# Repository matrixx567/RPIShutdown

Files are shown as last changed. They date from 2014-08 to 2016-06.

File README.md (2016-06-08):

RPIShutdown
===========



RPIShutdown adds a power switch to the Raspberry Pi. So it is possible to completely 
disconnect the Pi from the electrical power source.

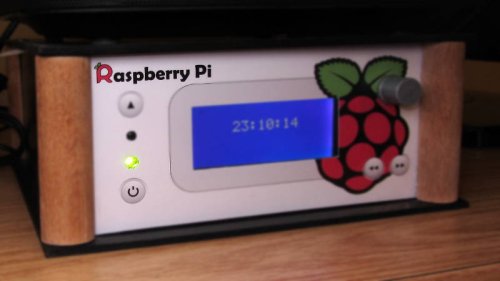
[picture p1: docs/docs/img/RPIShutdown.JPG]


How it works?
-------------
It works in the same way as the power button in the desktop computer will do.

Usually the Raspberry Pi isn't powered. If the button is pressed, the Raspberry Pi will be started.
The next press will smoothly shutdown the PI by running the `halt` command.  
If you press the button for about 4 seconds the Raspberry Pi will be hardly shutdown by 
disconnecting the power.

Installation
-------------
More information is available in the [installation notes](http://rpishutdown.readthedocs.org/content/installation-notes.html) in the documentation.

Documentation
--------------
More information are available in the [project documentation](http://rpishutdown.readthedocs.org).

other Projects
--------------

[ATXRaspi](http://lowpowerlab.com/atxraspi/): Has nearly the same functionality and you can buy it. 
But it isn't open source.

[PI2RMini](https://awjlogan.wordpress.com/2014/03/01/pi2rmini-a-proper-power-switch-for-the-raspberrypi/)

License
--------------
The MIT License (MIT)

Copyright (c) 2013 Martin Noehrer

Permission is hereby granted, free of charge, to any person obtaining a copy of
this software and associated documentation files (the "Software"), to deal in
the Software without restriction, including without limitation the rights to
use, copy, modify, merge, publish, distribute, sublicense, and/or sell copies of
the Software, and to permit persons to whom the Software is furnished to do so,
subject to the following conditions:

The above copyright notice and this permission notice shall be included in all
copies or substantial portions of the Software.

THE SOFTWARE IS PROVIDED "AS IS", WITHOUT WARRANTY OF ANY KIND, EXPRESS OR
IMPLIED, INCLUDING BUT NOT LIMITED TO THE WARRANTIES OF MERCHANTABILITY, FITNESS
FOR A PARTICULAR PURPOSE AND NONINFRINGEMENT. IN NO EVENT SHALL THE AUTHORS OR
COPYRIGHT HOLDERS BE LIABLE FOR ANY CLAIM, DAMAGES OR OTHER LIABILITY, WHETHER
IN AN ACTION OF CONTRACT, TORT OR OTHERWISE, ARISING FROM, OUT OF OR IN
CONNECTION WITH THE SOFTWARE OR THE USE OR OTHER DEALINGS IN THE SOFTWARE.

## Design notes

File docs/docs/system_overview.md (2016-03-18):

Hardware
========

Schematic
---------

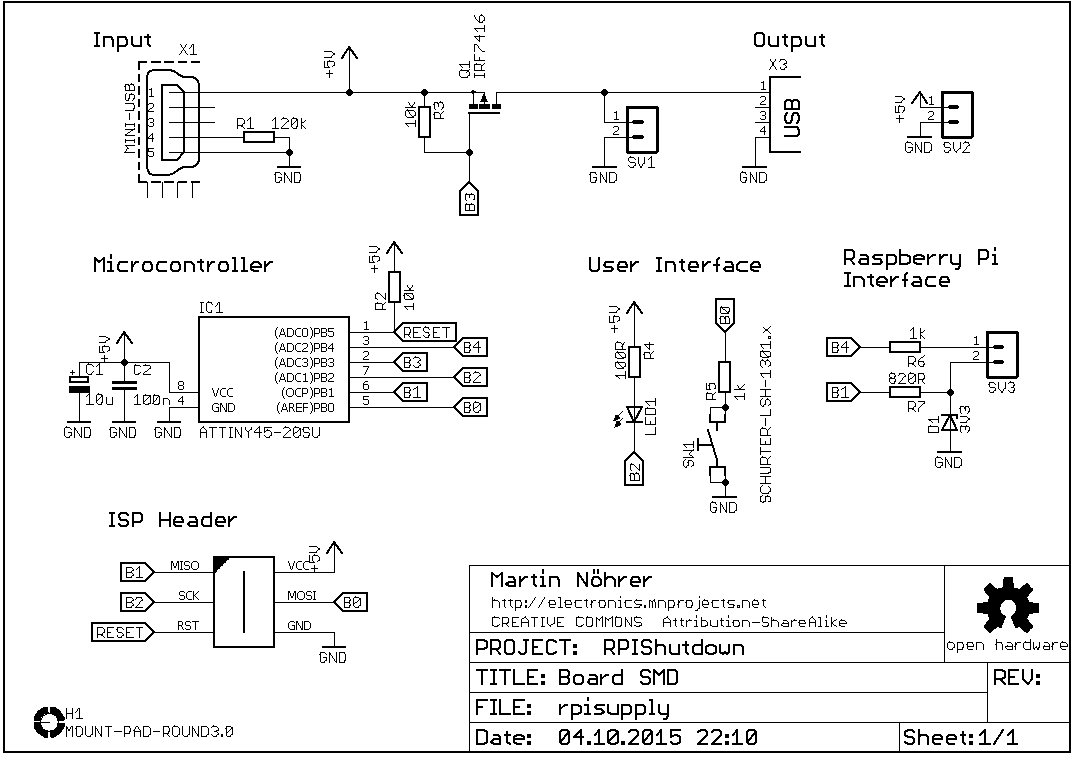
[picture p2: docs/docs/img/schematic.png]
Schematic


Description
-----------

Bill of materials
-----------------

| Qty | Part | Device | Value | VID | Vendor Part Num |
| ----- | --- | --- | --- | --- | --- |
| 1 | C1 | Cap pol | 10u | [RE] | SMD TAN.10/16 |
| 1 | C2 | Cap | 100n | [RE] | X7R-G0805 100N |
| 1 | D1 | Zener Diode | 3V3 | [RE] | SMD ZF 3,3 |
| 1 | IC1 | MC | ATTINY45-20SU | [RE] | ATTINY 45-20SU |
| 1 | LED1 | LED | green | [RE] | SMD-LED 0805 GN |
| 1 | Q1 | P-MOSFET | IRF7416 | [RE] | IRF 7416 |
| 1 | R1 | RES | 120k | [RE] | SMD-0805 120K |
| 2 | R2,R3 | RES | 10k | [RE] | SMD-0805 10,0K |
| 1 | R4 | RES | 100R | [RE] | SMD-0805 100 |
| 2 | R5,R6 | RES | 1k | [RE] | SMD-0805 1,00K |
| 1 | R7 | RES | 820R | [RE] | SMD-0805 820 |
| 1 | SW1 | Switch | SCHURTER-LSH-1301.x | [RE] | TASTER 9319 |
| 1 | X1 | Connector | MINI-USB | [RE] | LUM 2486-01 |
| 1 | X2 | Connector | AVR-ISP-6-EDGE | [RE] | MPE 087-2-006 |
| 1 | X3 | Connector | USB-A female | [RE] | USB AW |

[RE]: http://www.reichelt.at

Microcontroller Software
========================

State Machine
-------------

Settings
--------

Raspberry PI Software
========================

The Raspberry PI runs a simple script that checks periodically the signal line
of the microcontroller.

The Python script uses the preinstalled GPIO library (Raspbian).
If the microcontroller sends a shutdown command to the Raspberry PI (input line `RPI_RX` goes high)
the script executes the halt command and turn off the Raspberry PI.

Running the shutdown script as a daemon
---------------------------------------

The source folder for the Raspberry PI software also contains a shell script, which is used
to set up the RPIShutdown software as a background daemon.

[Original Script](http://blog.scphillips.com/2013/07/getting-a-python-script-to-run-in-the-background-as-a-service-on-boot/)

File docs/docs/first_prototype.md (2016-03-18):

First Prototype
========================

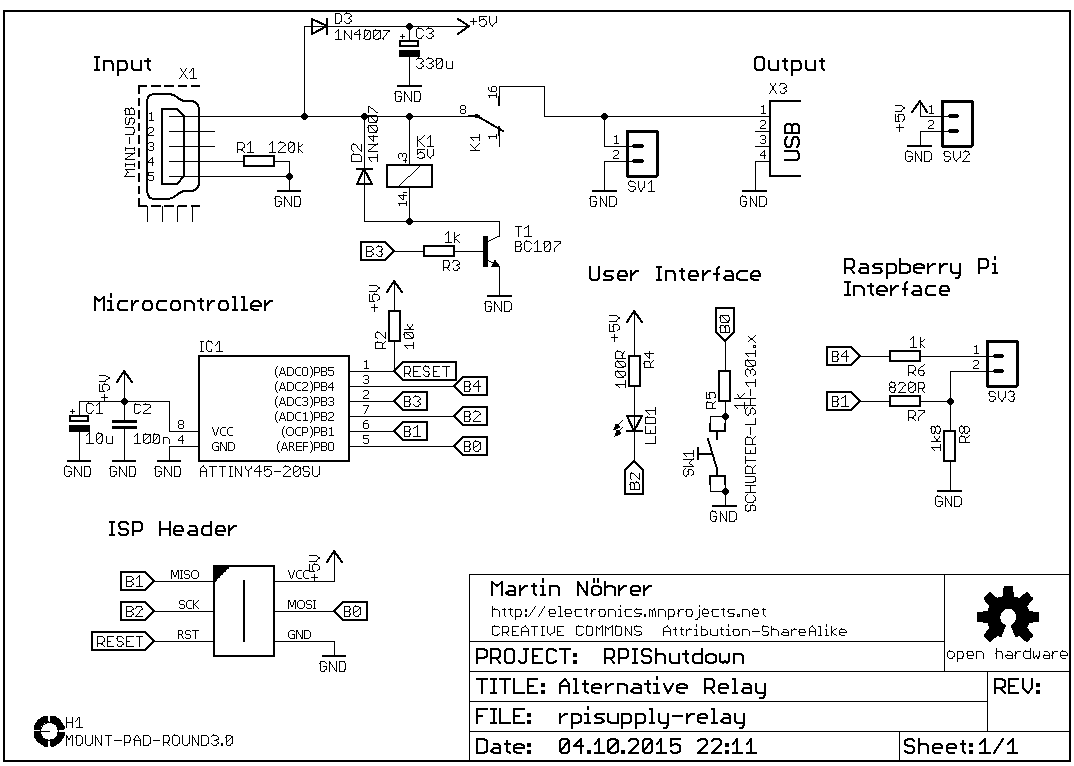
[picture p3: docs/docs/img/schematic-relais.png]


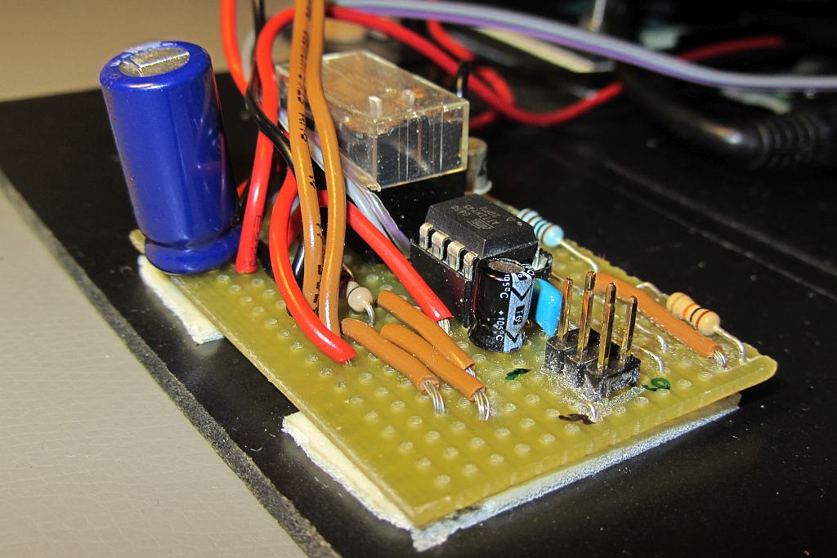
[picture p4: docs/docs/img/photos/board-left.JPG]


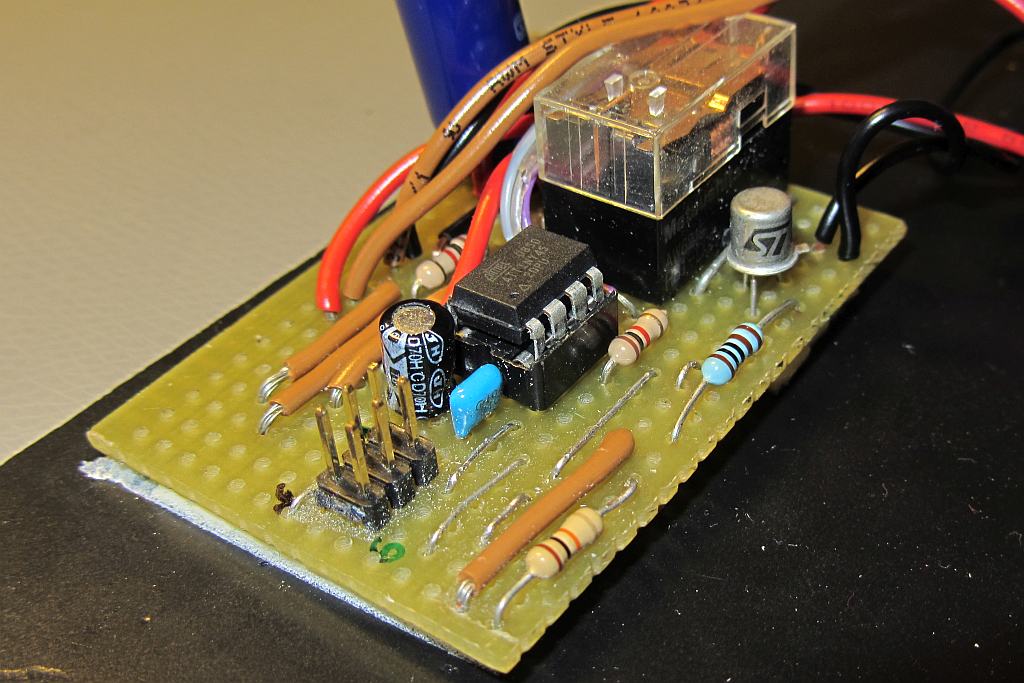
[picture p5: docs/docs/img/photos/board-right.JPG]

   
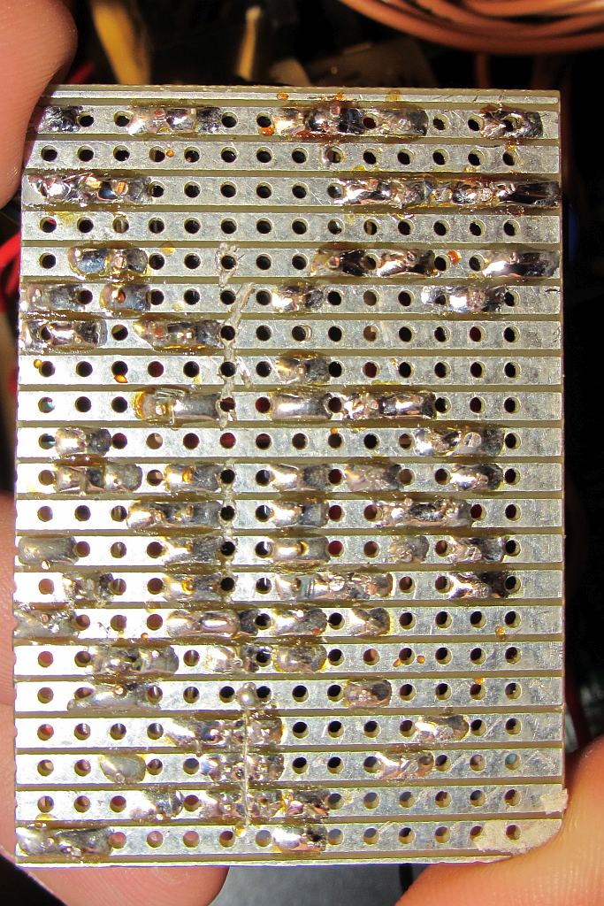
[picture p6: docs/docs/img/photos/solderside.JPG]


Microcontroller Reset Problems
------------------------------

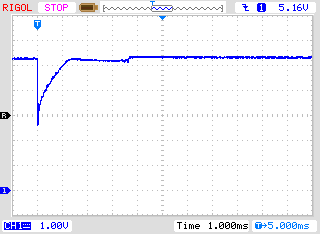
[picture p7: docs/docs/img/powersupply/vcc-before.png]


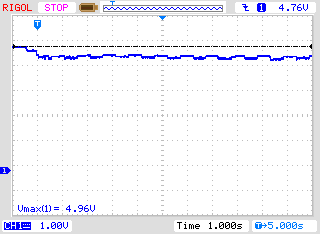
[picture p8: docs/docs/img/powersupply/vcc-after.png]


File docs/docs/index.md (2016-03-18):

RPIShutdown’s documentation!
============================

RPIShutdown adds a power switch to the Raspberry Pi. So it is possible to completely disconnect the Pi from the electrical power source.

RPIShutdown built in the RPIMpdBox

How it works?
-------------

It works in the same way as the power button in the desktop computer will do.

Usually the Raspberry Pi isn’t powered. If the button is pressed, the Raspberry Pi will be started. The next press will smoothly shutdown the PI by running the halt command. If you press the button for about 4 seconds the Raspberry Pi will be hardly shutdown by disconnecting the power.

Contents
--------

License
-------

This project is licensed under **The MIT License (MIT)**. More details will be available in the [license section](license.md).

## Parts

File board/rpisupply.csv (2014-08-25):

Bill of Materials from rpisupply.sch, 21 parts, grouped by values, as of 14.11.2013 10:41:19
Qty | Part | Value | Device | Package | Description | VID | Vendor Part Num | Description
1 | C1 | 10u | CPOL-EUSMCC | SMC_C | POLARIZED CAPACITOR, European symbol | RE | SMD TAN.10/16
1 | C2 | 100n | C-EUC0805 | C0805 | CAPACITOR, European symbol | RE | X7R-G0805 100N
1 | D1 | 3V3 | ZENER-DIODESOD80C | SOD80C | Z-Diode | RE | SMD ZF 3,3
1 | H1 | MOUNT-PAD-ROUND3.0 | MOUNT-PAD-ROUND3.0 | 3,0-PAD | MOUNTING PAD, round
1 | IC1 | ATTINY45-20SU | TINY25/45/85-20SU | SOIC8 |  | RE | ATTINY 45-20SU
1 | LED1 |  | LEDSML0805 | SML0805 | LED | RE | SMD-LED 0805 GN
1 | Q1 | IRF7416 | P-MOSFET-SO8 | SO-08 | P-Channel MOSFET | RE | IRF 7416 | Leistungs-MOSFET P-Ch SO-8 30V 10A
1 | R1 | 120k | R-EU_R0805 | R0805 | RESISTOR, European symbol | RE | SMD-0805 120K
2 | R2, R3 | 10k | R-EU_R0805 | R0805 | RESISTOR, European symbol | RE | SMD-0805 10,0K
1 | R4 | 100R | R-EU_R0805 | R0805 | RESISTOR, European symbol | RE | SMD-0805 100
2 | R5, R6 | 1k | R-EU_R0805 | R0805 | RESISTOR, European symbol | RE | SMD-0805 1,00K
1 | R7 | 820R | R-EU_R0805 | R0805 | RESISTOR, European symbol | RE | SMD-0805 820
3 | SV1, SV2, SV3 |  | MA02-1R | MA02-1
1 | SW1 | SCHURTER-LSH-1301.x | SCHURTER-LSH-1301.9319 | LSH | Schurter LSH Printmount Switches, Gullwing Leads [SMT] | RE | TASTER 9319
1 | X1 | MINI-USB | MINI-USB-SHIELD-UX60-MB-5ST | UX60-MB-5ST | MINI USB Connector | RE | LUM 2486-01 | MINI-USB
1 | X2 | AVR-ISP-6-EDGE | AVR-ISP-6-EDGE | 6PAD_ISP | 6 pin edge connector for ISP with ATMEL MCUs. | RE | MPE 087-2-006
1 | X3 |  | PN87520 | PN87520 | BERG USB connector | RE | USB AW | USB-A-female

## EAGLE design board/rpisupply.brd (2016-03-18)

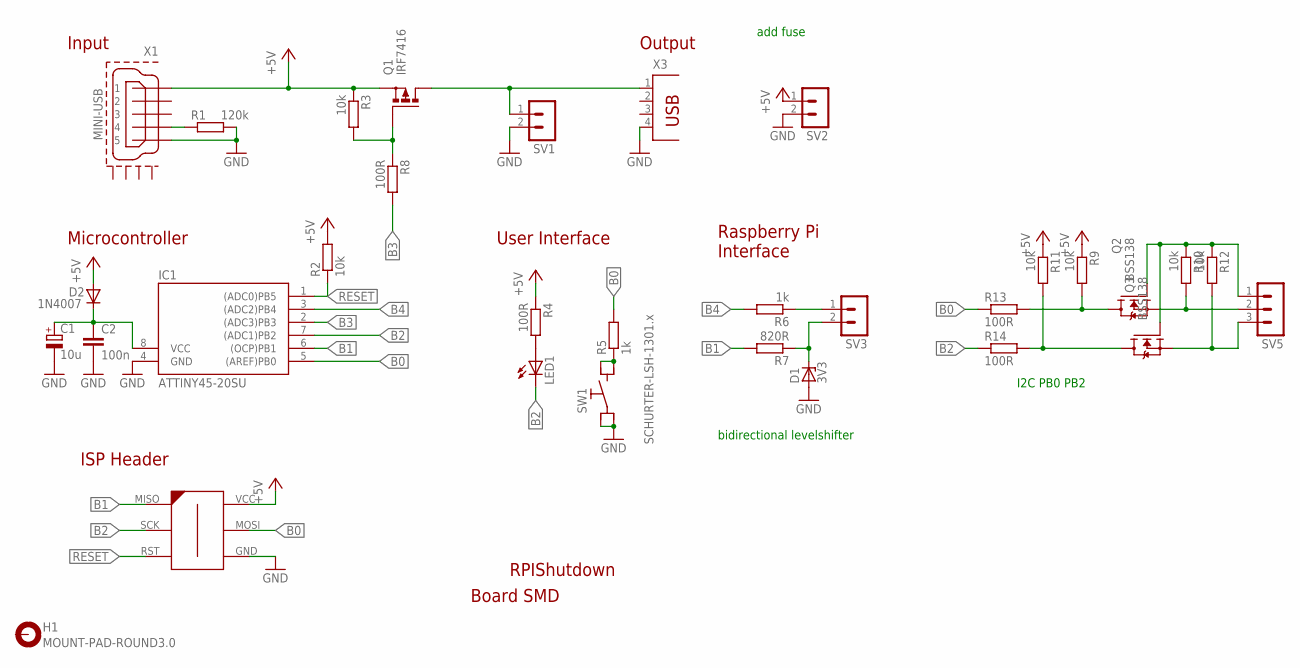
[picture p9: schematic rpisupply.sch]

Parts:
C1: 10u; SMC_C
C2: 100n; C0805
D1: 3V3; SOD80C
D2: 1N4007; MELF-MLL41
H1: MOUNT-PAD-ROUND3.0; 3,0-PAD
IC1: ATTINY45-20SU; SOIC8
LED1: LEDSML0805; SML0805
Q1: IRF7416; SO-08
Q2, Q3: BSS138; SOT23
R1: 120k; R0805
R2, R3, R9, R10, R11, R12: 10k; R0805
R4, R8, R13, R14: 100R; R0805
R5, R6: 1k; R0805
R7: 820R; R0805
SV1, SV2, SV3: MA02-1R; MA02-1
SV5: MA03-1R; MA03-1
SW1: SCHURTER-LSH-1301.x; LSH
X1: MINI-USB; UX60-MB-5ST
X2: AVR-ISP-6-EDGE; 6PAD_ISP
X3: PN87520

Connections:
+5V: D2.A, Q1.1 (S), Q1.2 (S), Q1.3 (S), R2.2, R3.1, R4.1, R9.1, R11.1, SV2.1, X1.1, X2.VCC
B0: IC1.5 ((AREF)PB0), R5.2, R13.1, X2.MOSI
B1: IC1.6 ((OCP)PB1), R7.2, X2.MISO
B2: IC1.7 ((ADC1)PB2), LED1.C, R14.1, X2.SCK
B3: IC1.2 ((ADC3)PB3), R8.2
B4: IC1.3 ((ADC2)PB4), R6.2
GND: C1.-, C2.2, D1.A, IC1.4 (GND), R1.2, SV1.2, SV2.2, SW1.C1 (C), SW1.C2 (C), X1.5, X2.GND, X3.4
unnamed: R6.1, SV3.1
unnamed: D1.C, R7.1, SV3.2
unnamed: R1.1, X1.4
unnamed: LED1.A, R4.2
unnamed: R5.1, SW1.NO1 (NO), SW1.NO2 (NO)
unnamed: Q1.4 (G), R3.2, R8.1
unnamed: C1.+, C2.1, D2.C, IC1.8 (VCC)
unnamed: Q2.1 (G), Q3.1 (G), R10.1, R12.1, SV5.1
unnamed: Q2.2 (S), R10.2, SV5.2
unnamed: Q3.3 (D), R11.2, R14.2
unnamed: Q3.2 (S), R12.2, SV5.3
unnamed: Q2.3 (D), R9.2, R13.2
unnamed: Q1.5 (D), Q1.6 (D), Q1.7 (D), Q1.8 (D), SV1.1, X3.1
RESET: IC1.1 ((ADC0)PB5), R2.1, X2.RST

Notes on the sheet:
RPIShutdown
Board SMD
ISP Header
Microcontroller
Raspberry Pi Interface
User Interface
Input
Output
bidirectional levelshifter
I2C PB0 PB2
add fuse

Board: 2 copper layers, 32 parts (0 on the bottom side), 21 nets, no tracks yet.

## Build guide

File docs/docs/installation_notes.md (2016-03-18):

Installation notes
==================

This page describes how to install the RPIShutdown to your Raspberry Pi.

Flashing the microcontroller
----------------------------

The code for the microcontroller must be compiled and flashed. In the
actual version the RPIShutdown uses a relais for switching the power of
the Raspberry Pi. The circuit is an open-collector output. The schematic derscribed in
[schematic] uses a P-Mosfet, so the code of the microcontroller must be
changed.

Connecting the RPIShutdown to the Raspberry Pi
----------------------------------------------

Note: Update electrical connections

Installing the Raspberry Pi daemon
----------------------------------

1. Copy `RPIShutdown.py` from `src_pi` to your HOME directory (e.g.`/home/pi`)
2. Move `RPIShutdown.sh` from `src_pi` to `/etc/init.d`
   `sudo mv RPIShutdown.sh /etc/init.d`
3. Change file attributes
   `sudo chmod 755 /etc/init.d/RPIShutdown.sh`
4. Startup the script
   `sudo service RPIShutdown.sh start`
5. Add script to startup
   `sudo update-rc.d RPIShutdown.sh defaults`

If you change the directory of `RPIShutdown.py`, you will also need to
change the path variable in `RPIShutdown.sh`.

With `sudo service RPIShutdown.sh status` the status of the daemon can
be checked.

Github Repository Structure
---------------------------

The project folder is organized in the following structure:

```
	RPIShutdown
	+--- board  (Schematics)
	+--- docs   (Documentation files for ReadTheDocs)
	+--- src    (Microcontroller software)
	\--- src_pi (Raspberry Pi software)
```
    
[schematic]: system_overview.md#Schematic

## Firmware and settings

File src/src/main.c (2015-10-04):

/************************************************************************
Project:  RPISupply
Title:    Add a supply switch to the raspberry pi
Author:   Martin Noehrer
Email:    martin@mnprojects.net
Homepage: https://github.com/matrixx567/RPIShutdown
File:     main.c
Date:

License:  MIT License

LICENSE:
Copyright (C) 2013 Martin Noehrer

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
THE SOFTWARE IS PROVIDED "AS IS", WITHOUT WARRANTY OF ANY KIND, EXPRESS 
OR IMPLIED, INCLUDING BUT NOT LIMITED TO THE WARRANTIES OF MERCHANTABILITY,
FITNESS FOR A PARTICULAR PURPOSE AND NONINFRINGEMENT. IN NO EVENT SHALL THE 
AUTHORS OR COPYRIGHT HOLDERS BE LIABLE FOR ANY CLAIM, DAMAGES OR OTHER 
LIABILITY, WHETHER IN AN ACTION OF CONTRACT, TORT OR OTHERWISE, ARISING 
FROM, OUT OF OR IN CONNECTION WITH THE SOFTWARE OR THE USE OR OTHER 
DEALINGS IN THE SOFTWARE.
 *************************************************************************
Software: WIN-AVR 20100110 - AVR-GCC 4.3.3, AVR Libc 1.6.7
Hardware: ATtiny45 at 8Mhz /DIV8 => 1MHz
Fuses:    LFUSE:62 HFUSE:DF EFUSE:FF
Fuses:    LFUSE:62 HFUSE:DD EFUSE:FF	new Setting
Usage:
 *************************************************************************
Pin Description:
B0: inp	Switch		 low...pressed
B1:	out	RPI-TX		 output to raspberrypi
B2:	out	Status-LED   low...LED on
B3:	out	Relay		 high...on
B4:	inp	RPI-RX		 input from raspberrypi
 *************************************************************************
Description: see documentation
 *************************************************************************
Changelog:
 *************************************************************************
contains code and ideas from:
 ************************************************************************/


 // #define USE_MOSFET

//internal 8MHz oscillator with CKDIV8
#ifndef F_CPU
#define F_CPU 1000000UL     /* 1 Mhz internal oscillator  */
#endif


#include <avr/io.h>
#include <avr/sleep.h>
#include <avr/interrupt.h>
#include <util/delay.h>


#define IRPIRX	PB4
#define ORELAY	PB3
#define OLED	PB2
#define ORPITX	PB1
#define ISWITCH	PB0


#ifdef USE_MOSFET
// use mosfet - active low
	#define RELAY_ON	PORTB &= ~(1<<ORELAY)
	#define RELAY_OFF	PORTB |= (1<<ORELAY)
#else
// use relay - active high
	#define RELAY_ON	PORTB |= (1<<ORELAY)
	#define RELAY_OFF	PORTB &= ~(1<<ORELAY)
#endif


//internal states
enum sm_states_e {
	POWER_OFF = 0,
	STARTUP,
	RUNNING,
	SHUTDOWN
};


// modes for the LED
enum led_mode_e {
	LED_OFF=0,
	LED_BLINKING,
	LED_ON
};


// states of the button
enum button_state_e{
	NO_PRESS = 0,
	SHORT_PRESS,
	LONG_PRESS
};

//direction of soft blinking LED
enum led_pwm_direction_e{
	COUNT_UP = 0,
	COUNT_DOWN
};

// counter for button's debouncing and for detecting the long press
volatile uint16_t button_cnt = 0;

// counter for detecting the delay timer overflows
volatile uint8_t delay_counter = 0;

// actual mode of the LED
volatile enum led_mode_e led_mode = LED_OFF;


//level value for soft emulated PWM
uint8_t softblink_level=0;

//direction of soft blinking LED
enum led_pwm_direction_e led_pwm_dir = COUNT_UP;

//step for softblinking LED
#define SOFTBLINK_STEP 2


/**
 * Interrupt service routine for Timer 0.
 *
 * This timer is used to detect a long press of the button
 */
ISR( TIMER0_OVF_vect )                   // every 16ms
{
	button_cnt++;


	if(led_pwm_dir == COUNT_UP){
		if(softblink_level> (255-SOFTBLINK_STEP) ){
			led_pwm_dir = COUNT_DOWN;
			softblink_level = 255;
		} else {
			softblink_level += SOFTBLINK_STEP;
		}
	} else {
		if(softblink_level<SOFTBLINK_STEP){
			led_pwm_dir = COUNT_UP;
			softblink_level = 0;
		} else {
			softblink_level -= SOFTBLINK_STEP;
		}
	}
}

/**
 * Interrupt service routine for Timer 1.
 *
 * This timer is used to generate delay functionality.
 */
ISR(TIMER1_OVF_vect) {				//every 500ms
	//if(led_mode == LED_BLINKING)
	//	PORTB ^= (1<<OLED);
	delay_counter++;
}


ISR(INT0_vect) {

}

ISR(PCINT0_vect) {

}



int main(void) {

	//internal actual state of the state machine
	enum sm_states_e states_e = POWER_OFF;

	//actual state of the button
	enum button_state_e buttonstate = NO_PRESS;

	//temporary state which is used for resetting the delay counter
	enum sm_states_e temp_states_e = POWER_OFF;


	//temporary value for soft emulated PWM
	uint8_t softblink_temp=0;



	//set direction of pins to output
	DDRB = (1 << ORELAY) | (1 << OLED) | (1 << ORPITX);

	RELAY_OFF;		//Switch off relay

	PORTB &= ~(1<<ORPITX);		//Switch off TX


	// Configure debouncing routines
	DDRB  &= ~(1<<ISWITCH);                // configure key port for input
	PORTB |= (1<<ISWITCH);                // and turn on pull up resistors

	TCCR0B = (1<<CS01)|(1<<CS00);         // divide by 64
	// overflow 0.016 sec

	TIMSK |= 1<<TOIE0;                   // enable timer interrupt

	TCCR1 |= (1<<CS13) |(1<<CS12); // Prescaler 2048
	// overflow time about 0.5 sec

	PCMSK |= (1<<PCINT0); //  tell pin change mask to listen to PB0, Switch
	PCMSK |= (1<<PCINT4); //  tell pin change mask to listen to PB4, RPIInput

	// Overflow Interrupt erlauben
	TIMSK |= (1<<TOIE1);
	GIMSK |= (1<<PCIE);
	sei();

	set_sleep_mode(SLEEP_MODE_PWR_DOWN);


	//Detecting reset of microcontroller - for debugging
	PORTB &= ~(1<<OLED);
	for(int i=0; i < 10 ; i++){
		PORTB ^= 1<<OLED;
		_delay_ms(100);
	}
	PORTB |= (1<<OLED);


	while (1) {



		buttonstate=NO_PRESS;

		if( !(PINB & (1<<ISWITCH )) ) {
			button_cnt=0;
			while(button_cnt < 6){	//wait for about 50ms - debouncing

			}
			while(!(PINB & (1<<ISWITCH ))){
				buttonstate=SHORT_PRESS;
				if(button_cnt >= 250){	//4sec long button press-shutdown
					buttonstate=LONG_PRESS;
					break;
				}
			}
		}


		temp_states_e = states_e;


		//state transition function
		switch(states_e) {
		case POWER_OFF:
			if ( SHORT_PRESS == buttonstate )
				states_e = STARTUP;
			break;
		case STARTUP:
			if( (PINB & (1<<IRPIRX)) && delay_counter >= 6 ) {
				states_e = RUNNING;
			}
			if( delay_counter >= 120 ) {
				states_e = RUNNING;
			}
			break;
		case RUNNING:
			if( !(PINB &(1<<IRPIRX))) {
				states_e = SHUTDOWN;
			}
			if( SHORT_PRESS == buttonstate ) {
				states_e = SHUTDOWN;
			}
			break;
		case SHUTDOWN:
			if( (PINB &(1<<IRPIRX)) && delay_counter >= 4 ) {
				states_e = RUNNING;
			}
			if((!(PINB &(1<<IRPIRX))) && delay_counter >= 40 ) {	//20sec
				states_e = POWER_OFF;
			}
			if( delay_counter >= 120 ) {
				states_e = POWER_OFF;
			}
			break;
		}


		if ( LONG_PRESS == buttonstate ) {
			states_e = POWER_OFF;
		}


		if( temp_states_e != states_e) {
			delay_counter = 0;
		}

		//output function
		switch(states_e) {
		case POWER_OFF:
			RELAY_OFF;
			PORTB &= ~(1<<ORPITX);		//Switch off TX
			led_mode = LED_OFF;
			break;
		case STARTUP:
			RELAY_ON;
			PORTB &= ~(1<<ORPITX);		//Switch off TX
			led_mode = LED_BLINKING;
			break;
		case RUNNING:
			RELAY_ON;
			PORTB &= ~(1<<ORPITX);		//Switch off TX
			led_mode = LED_ON;
			break;
		case SHUTDOWN:
			RELAY_ON ;
			PORTB |= (1<<ORPITX);		//Switch on TX
			led_mode = LED_BLINKING;
			break;
		}


		//LED control functionality
		if(led_mode == LED_ON) {
			PORTB &= ~(1<<OLED);

			led_pwm_dir=COUNT_DOWN;
			softblink_level=255;

		} else if (led_mode == LED_OFF) {
			PORTB |= (1<<OLED);

			led_pwm_dir=COUNT_UP;
			softblink_level=0;

		} else if (led_mode == LED_BLINKING){
			//use a software emulated PWM to generate a soft blinking LED for startup
			if(softblink_temp < softblink_level) {
				PORTB |= (1<<OLED);
			} else {
				PORTB &= ~(1<<OLED);
			}
			softblink_temp++;
		}


		while(LONG_PRESS == buttonstate && (!(PINB & (1<<ISWITCH )))){	//if long button press
																//wait for release
		}



		cli();
		if (states_e == POWER_OFF || states_e == RUNNING) {
			sleep_enable();
			sei();
			sleep_cpu();
			sleep_disable();

			//sleep wakeup
			delay_counter = 0;
		}
		sei();


	}

	return 0;
}

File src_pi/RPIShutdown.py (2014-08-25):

#!/usr/bin/env python

#import
import RPi.GPIO as GPIO
import time
import os

# Define GPIO to uC
RPI_TX = 30
RPI_RX = 28

def main():
    # Main program block

    GPIO.setmode(GPIO.BCM)       # Use BCM GPIO numbers
    GPIO.setup(RPI_RX,GPIO.IN)
    GPIO.setup(RPI_TX,GPIO.OUT)
    print("Shutdown Script: Startup")
    GPIO.output(RPI_TX, True)
    while True:
        if(GPIO.input(RPI_RX)):
            GPIO.output(RPI_TX,False)
            print("Shutdown Script: Shutdown")
            os.system("sudo shutdown -h now")
            break
        time.sleep(1)
    GPIO.output(RPI_TX,False)
    GPIO.cleanup();

if __name__ == '__main__':
    main()

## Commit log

2014-08-25 Repository reinitialization
    [rpisupply-relay.sch, rpisupply.brd, rpisupply.csv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]
2015-07-27 add images for documentation
    [rpisupply-relay.sch]
2015-10-04 Change frame in schematics
    [rpisupply-relay.sch, rpisupply.sch]
2016-03-08 add bidirectional levelshifter
    [rpisupply.brd, rpisupply.sch]
2016-03-15 add components for next version
    [rpisupply.brd, rpisupply.sch]
2016-03-18 change docs to mkdocs
    [rpisupply.brd, rpisupply.sch]

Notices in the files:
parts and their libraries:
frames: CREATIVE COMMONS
